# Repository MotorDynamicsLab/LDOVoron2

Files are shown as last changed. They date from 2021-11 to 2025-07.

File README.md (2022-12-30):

# LDO Voron 2 Kit
This repository contains supplementary information/configuration/3d models for the LDO Voron 2 Kit.

We would thank the Voron Design team for all of their hard work and contributions to the 3D printing community.

This repo contains both original and derivative works from the Voron project, 
which is licensed GPLv3. This repo therefore is also licensed under the terms 
of the GNU Public License, verison 3.

GPLv3 License Attributions:

https://github.com/VoronDesign/Voron-Trident
https://github.com/VoronDesign/Voron-2
https://github.com/VoronDesign/Voron-Stealthburner

For more information and support:

https://vorondesign.com

https://discord.gg/voron

https://docs.ldomotors.com

https://www.ldomotion.com

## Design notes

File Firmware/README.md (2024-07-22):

# LDO Voron 2 Configs

## octopus-printer-rev-a.cfg

This contains mainboard configs for LDO V2.4 kits Rev.A & Rev.B

## octopus-printer-rev-c.cfg

This contains mainboard configs for LDO V2.4 kits Rev.C. Changes include:

- Disable mini12864 display, kit now uses a 4.3inch touch panel
- Change chamber thermistor type to ATC Semitec 104NT, kit now uses externally mounted thermistor
- Change extruder gear ratio to 50:10, kit now ships with clockwork 2 by default
- Add configs for Stealthburner neopixels

## leviathan-printer-rev-d.cfg

This contains mainboard configs for LDO V2.4 kits Rev.D

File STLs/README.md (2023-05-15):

# STLs for LDO Kit
This directory contains STL files specific to the LDO kit.

## Plug Panel 1.2mm (Deprecated as of V2.4R2)
This part replaces the `plug_panel` part from the official [Voron repo](https://github.com/VoronDesign/Voron-2/tree/Voron2.4/STLs/VORON2.4/Electronics_Compartment/Plug_Panel). This part adapts specifically to 1.2mm AC inlets for a better fit.

## Nozzle Probe LDO
This part replaces the `nozzle_probe` part from the official [Voron repo](https://github.com/VoronDesign/Voron-2/tree/Voron2.4/STLs/VORON2.4/Z_Endstop). This part allows for an LDO Z Endstop PCB to be used.

## Handlebar Spacer
This optional part offsets the top panel thickness and helps mount the included aluminium handle bar.

## Z Rail stop
An optional part that stops the linear rail carts from falling off the Z rails.

## Exhaust Cover
If you decide to build the Nevermore internal circulation filter, print this exhaust cover to seal the back panel.

## LED PCB Spacer
This part helps mount the LED splitter PCB to the 2020 extrusion.

## Toolhead Breakout PCB Bracket
This part helps mount the toolhead breakout PCB. Print an additional DIN rail clip to attach to this part.

## LDO Bestagon Insert
An (optional) LDO Logo that inserts into the hexagonal holes of the skirts.

## Beefy Raspberry Pi Mount
This mount uses two DIN clips for a more secure grip on DIN rails. 

## Z Belt Cover A LED
This is a remix of the original Z Belt Cover but leaves a small opening for the LED cable to pass through.

## CW2 Offset Chain Anchor
This is the same part as the official chain anchor with an additional M3 insert hole that offsets the end of the X cable chain slightly. Moving the left two holes may result in better clearance when using the cable chain provided in the LDO V2 or Trident kits.

## CW2 PCB Cover for Captive Screw
This part is a slight modification of hartk's [Clockwork 2 PCB cover with thermistor](https://github.com/VoronDesign/Voron-Hardware/blob/master/Stealthburner_Toolhead_PCB/STLs/cable_cover_pcb_with_thermistor.stl). It is designed to be used in conjunction with a captive M3x8 screw, so that the screw does not fall out when the PCB cover is opened.

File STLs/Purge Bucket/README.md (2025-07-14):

# Nozzle scrubber
Our kits provide a brass brush which you can use to convert to a nozzle scrubber using this [mod](https://github.com/VoronDesign/VoronUsers/tree/main/orphaned_mods/edwardyeeks/Decontaminator_Purge_Bucket_%26_Nozzle_Scrubber).
Since our build plate sits higher than typical voron beds, you should use modified files here.

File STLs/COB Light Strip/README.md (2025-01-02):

# COB Light Strip Mount
This is an easy and fast to print mount for COB (chip on the board) LED strips, which are included in LDO Voron kits starting from Rev.D. These LED strips have built-in light diffusion which produces a softer lighting effect for your printer. 
- The STLs come in three sizes (50/100/150mm) that allow you to combine into different lengths to match your LED strip. 
- The provided Fusion 360 source file is parametric to allow for any arbitrary length for the mount. 

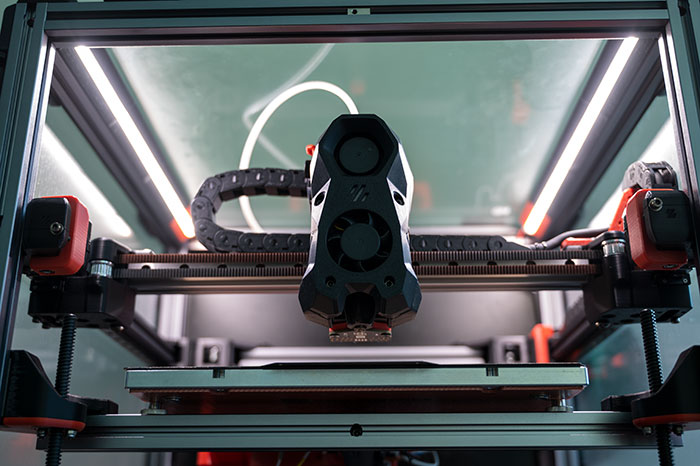
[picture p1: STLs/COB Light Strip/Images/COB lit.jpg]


## Printing for LDO kits
The following are recommend print counts for different LDO Voron kits. Note that you can always substitude 50mm variant and 100mm variant with a single 150mm variant.

### Voron 2.4-300 Kit
Print 6x cob_light_strip_mount_100mm 

### Voron 2.4-350 Kit
Print 6x cob_light_strip_mount_100mm + 2x cob_light_strip_mount_50mm

### Voron Trident-250 Kit
Print 6x cob_light_strip_mount_100mm + 2x cob_light_strip_mount_50mm

### Voron Trident-300 Kit
Print 8x cob_light_strip_mount_100mm

## Assembly
Each mount is a two piece assembly (for easy printing). Use 2x M3 Heatsets and 2x M3x6 FHCS screws two assemble the two pieces together. Use 2x M3x8 SHCS to install the part to the side of a 2020 extrusion.

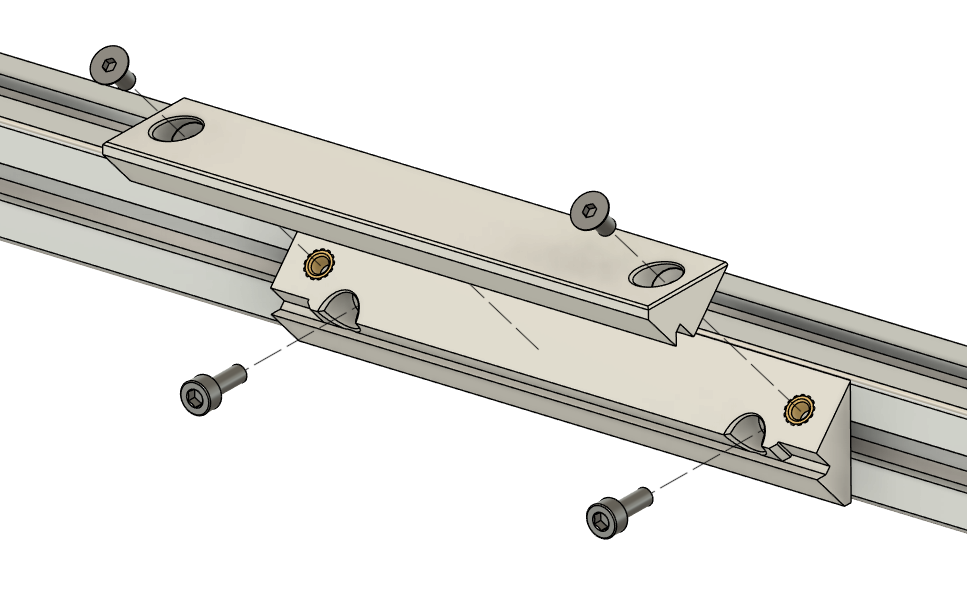
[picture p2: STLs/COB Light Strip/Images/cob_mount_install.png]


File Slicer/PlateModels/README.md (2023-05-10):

# Slicer Plate Models & Textures
This folder contains models and textures that can be used in SuperSlicer or PrusaSlicer. Open Printer Settings->General->Bed Shape. 
- Under Texture, select the svg file appropriate to your build plate size ("300_ldo_texture.svg" for a 300mm plate)
- Under Model, select the stl file appropriate to your build plate size ("Voron_300_Build_Plate.stl" for a 300mm plate)

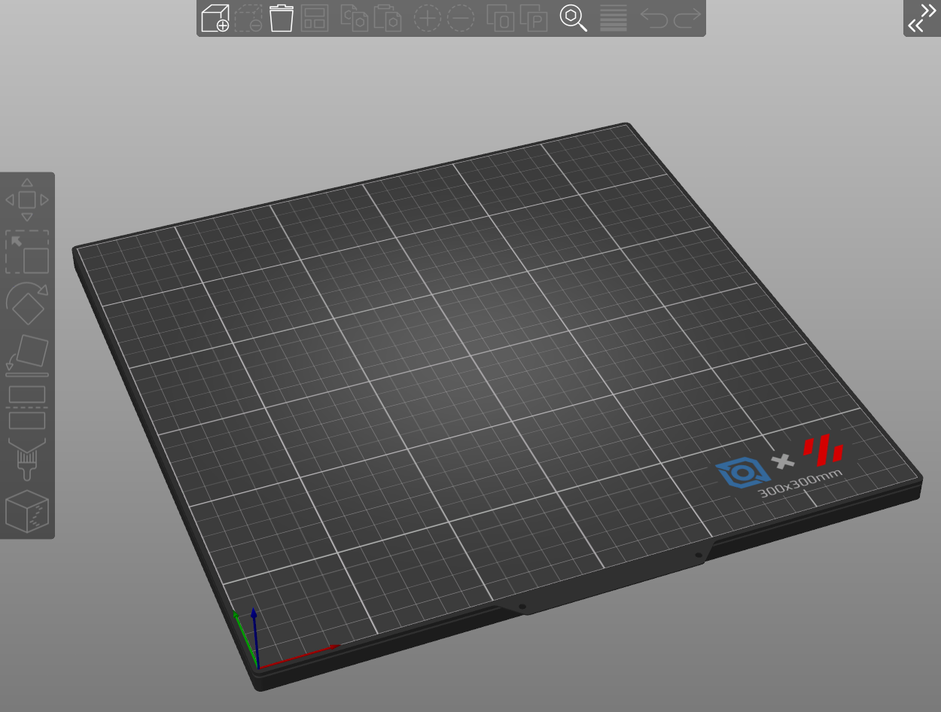
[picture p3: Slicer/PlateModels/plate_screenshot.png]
Screenshot of the LDO custom slicer plate


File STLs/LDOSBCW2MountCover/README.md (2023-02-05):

# LDO Steathburner + Clockwork 2 + LDO Toolhead PCB

## THIS MOD NO LONGER REQUIRED for LDO V2.4 Rev. C - the kit includes the Stealthburner PCBs and works with the stock parts.

For assembly directions please follow our guide [LDO Motion](https://www.ldomotion.com/p/guide/18295873486194241).

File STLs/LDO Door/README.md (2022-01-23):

# LDO Door
This directory contains STL files for an alternative door mounting design.

## Screw Hinge
The screw hinge uses M3 screws instead of a print in place hinge design. We recommend using three hinges per door. M3x40 SHCS screws are recommended, however M3x30 or Mx35 screws also work. 

## Handles
These handles are of the same design as the original voron door handles but longer. handle_a and handle_b are simply mirrors of each other. handle_b_nameplate contains a recess to embed an LDO kit number nameplate (use superglue to attach the nameplate).

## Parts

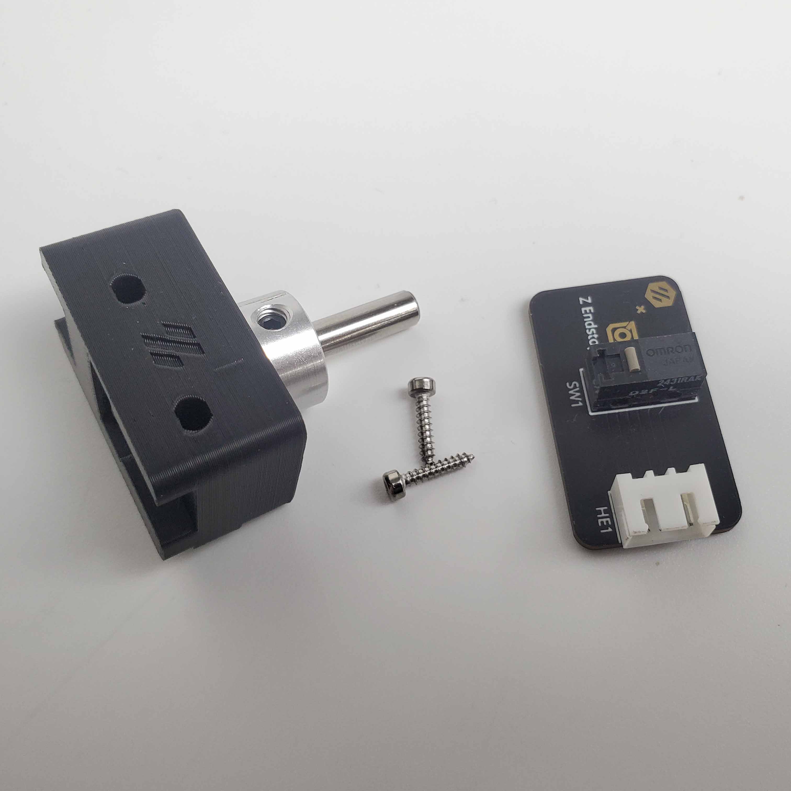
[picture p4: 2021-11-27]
Images/WiringGuide/z_stop_parts.jpg

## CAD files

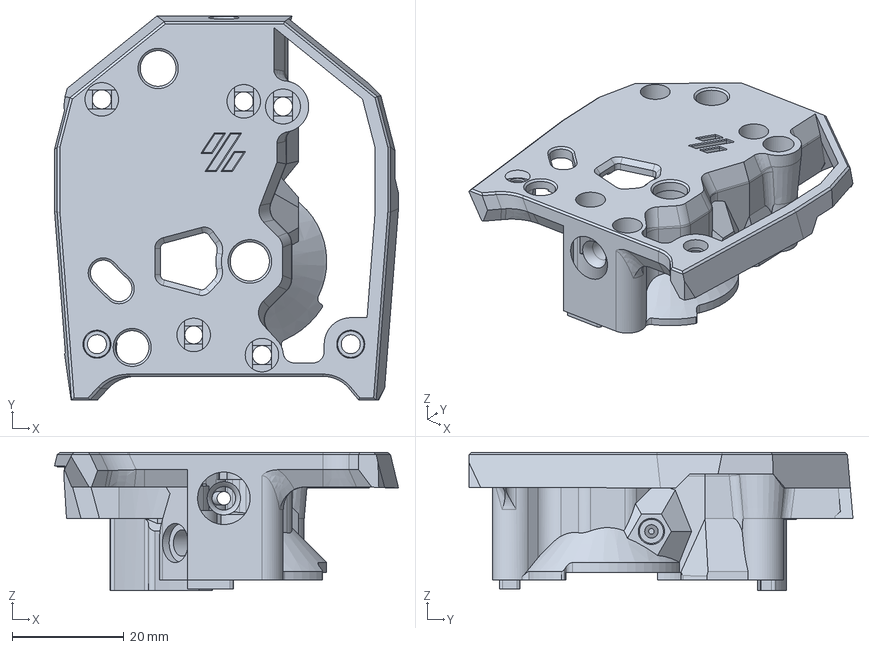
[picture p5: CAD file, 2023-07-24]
STLs/LDOSBCW2MountCover/main_body.step
61.5 x 68.7 x 24.7 mm
LDO AB PCB Assembly

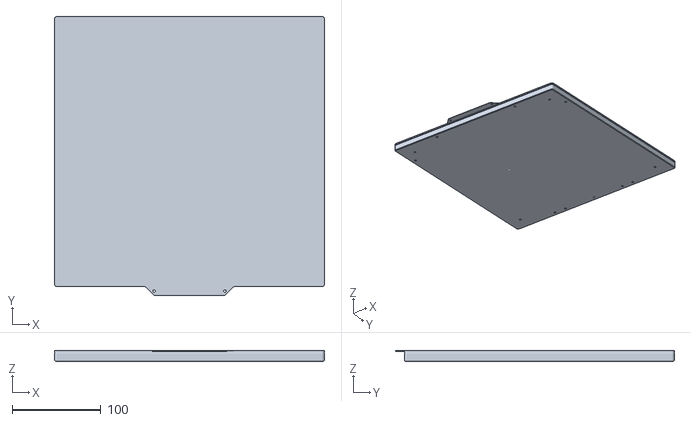
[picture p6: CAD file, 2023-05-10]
Slicer/PlateModels/Voron_300_Build_Plate.stl
305.0 x 315.0 x 11.9

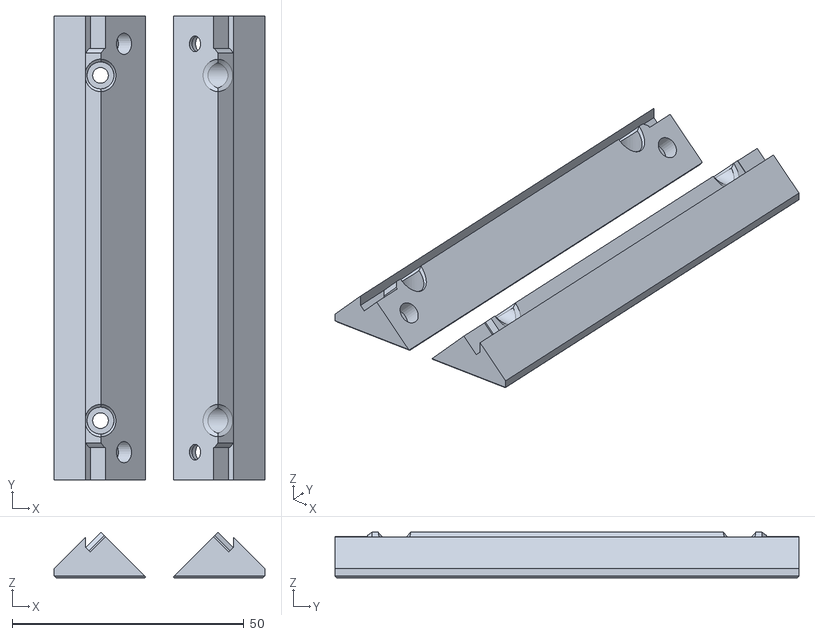
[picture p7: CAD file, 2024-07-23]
STLs/COB Light Strip/cob_light_strip_mount_100mm.stl
45.4 x 100.0 x 9.87

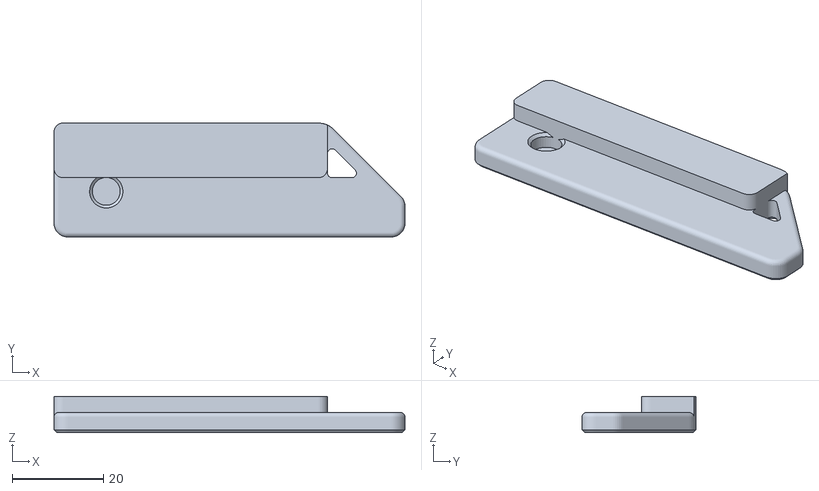
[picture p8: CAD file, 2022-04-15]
STLs/LDO Door/handle_b_nameplate.stl
77.0 x 25.0 x 7.90

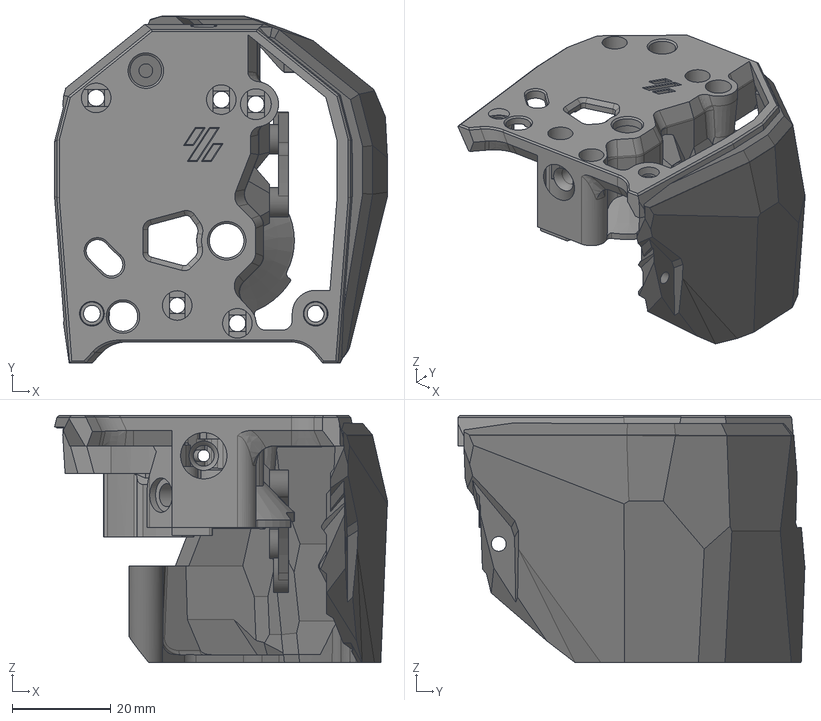
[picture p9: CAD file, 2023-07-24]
STLs/LDOSBCW2MountCover/Stealthburner_CW2_LDOPCB.step
67.6 x 70.4 x 50.2 mm
pcb_spacer v2 v9
cable_cover_for_pcb v9
main_body

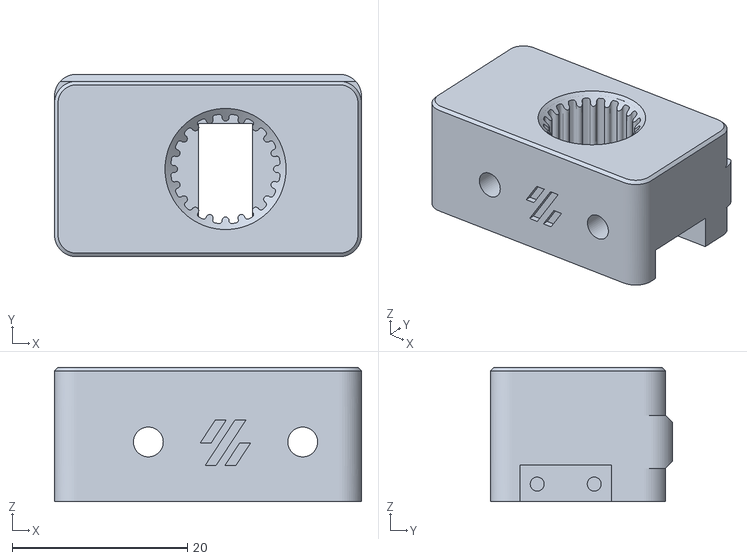
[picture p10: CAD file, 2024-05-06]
STLs/nozzle_probe_ldo.stl
35.0 x 20.8 x 15.3

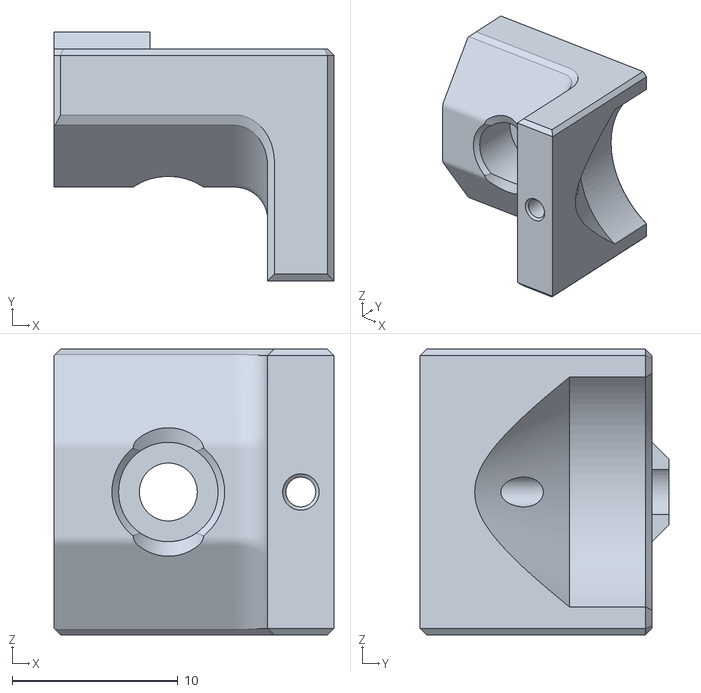
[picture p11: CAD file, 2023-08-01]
STLs/Purge Bucket/individual_sheet_stop.stl
16.9 x 15.0 x 17.3

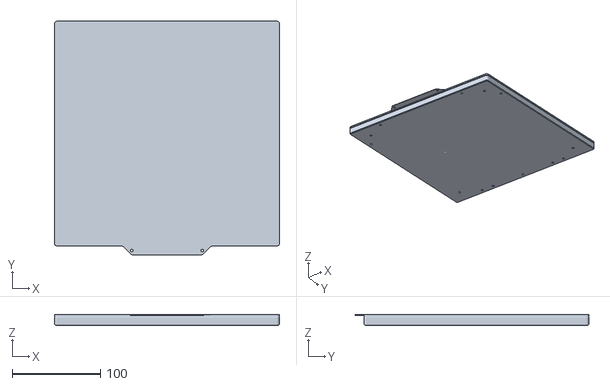
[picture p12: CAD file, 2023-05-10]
Slicer/PlateModels/Voron_250_Build_Plate.stl
255.0 x 265.0 x 11.9

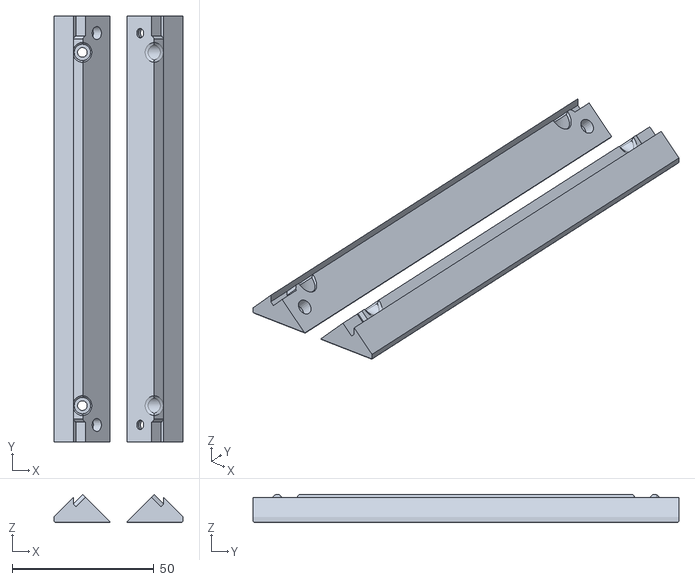
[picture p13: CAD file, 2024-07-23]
STLs/COB Light Strip/cob_light_strip_mount_150mm.stl
45.4 x 150.0 x 9.87

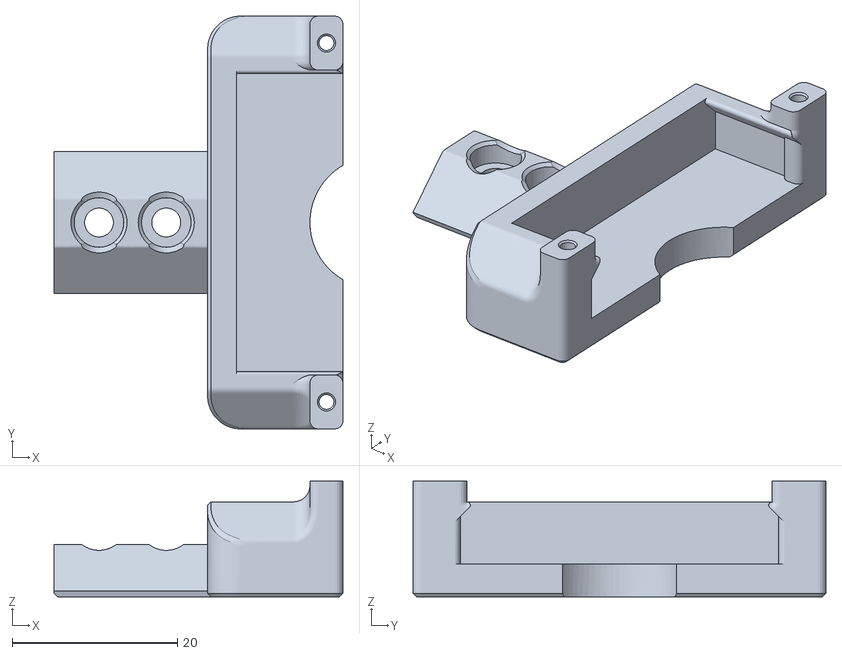
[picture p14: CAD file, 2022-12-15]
STLs/Purge Bucket/brush_holder_sheet_stop.stl
35.0 x 50.0 x 14.0

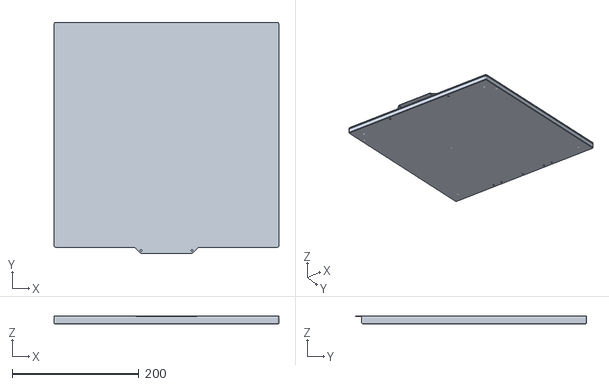
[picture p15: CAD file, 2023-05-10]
Slicer/PlateModels/Voron_350_Build_Plate.stl
355.0 x 365.0 x 11.9

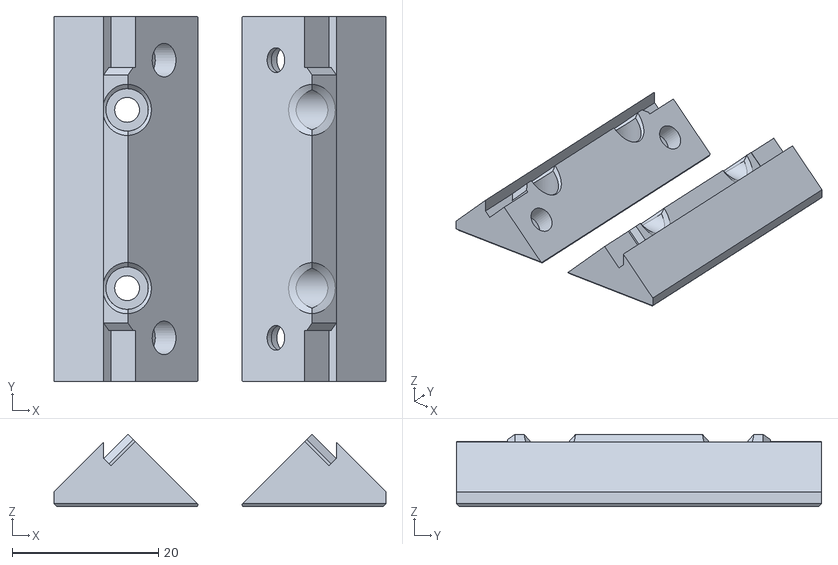
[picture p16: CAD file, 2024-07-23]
STLs/COB Light Strip/cob_light_strip_mount_50mm.stl
45.4 x 50.0 x 9.87

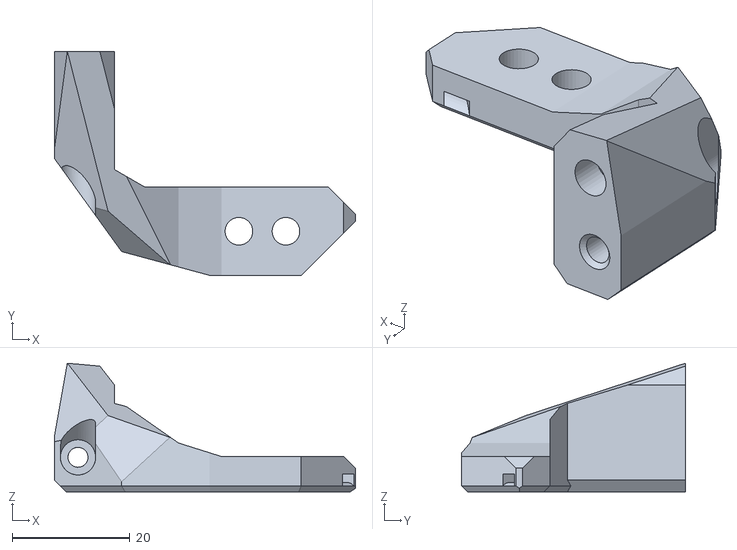
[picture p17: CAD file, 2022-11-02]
STLs/cw2_offset_chain_anchor.stl
51.2 x 38.0 x 21.9

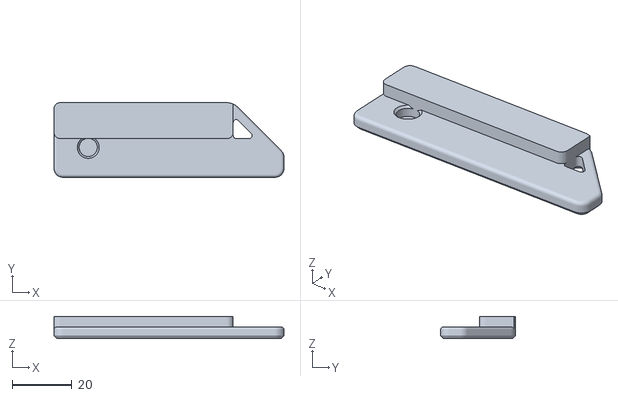
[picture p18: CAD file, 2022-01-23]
STLs/LDO Door/handle_b.stl
77.0 x 25.0 x 7.50

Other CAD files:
STLs/LDOSBCW2MountCover/pcb_spacer.step
STLs/LDO Door/handle_a_x2.stl
STLs/LDOSBCW2MountCover/cable_cover_for_pcb.step
STLs/z_belt_cover_a_led.stl
STLs/Beefy Raspberry Bracket.f3d
STLs/COB Light Strip/COB Light Strip Mount.f3d
STLs/CW2 Offset Chain Anchor.f3d
STLs/CW2 PCB Cover for Captive Screw.f3d
STLs/Exhaust Cover.f3d
STLs/Handlebar Spacer.f3d
STLs/LDO Bestagon Insert.f3d
STLs/LDO Door/Handle Nameplate.f3d
STLs/LDO Door/Handle.f3d
STLs/LDO Door/Screw Hinge.f3d
STLs/LDO Door/screw_hinge_x3.stl
STLs/LDOSBCW2MountCover/LDOSBCW2Cover.step
STLs/LDOSBCW2MountCover/LDOSBCW2Cover.stl
STLs/LDOSBCW2MountCover/LDOSBCW2Mount.step
STLs/LDOSBCW2MountCover/LDOSBCW2Mount.stl
STLs/LDOSBCW2MountCover/LDOSBCW2MountCover.3mf
STLs/LDOSBCW2MountCover/Stealthburner_CW2_LDOPCB.3mf
STLs/LDOSBCW2MountCover/cable_cover_for_pcb.stl
STLs/LDOSBCW2MountCover/deprecated/LDOSBCW2Cover.step
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

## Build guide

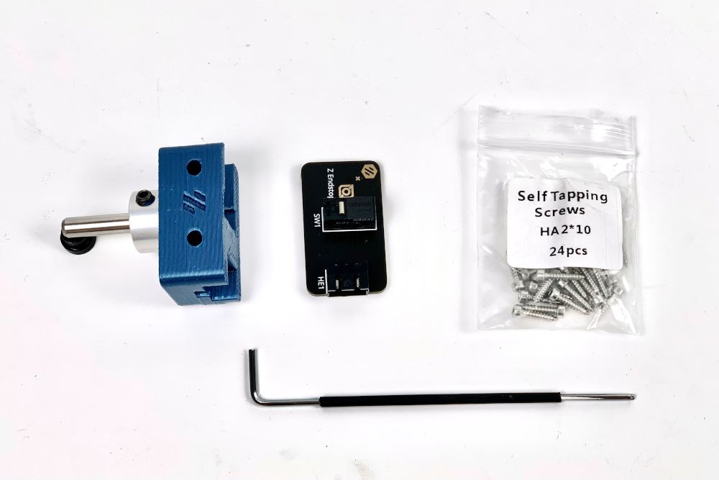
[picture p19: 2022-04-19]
Images/WiringGuide/z_stop_install_1.jpg

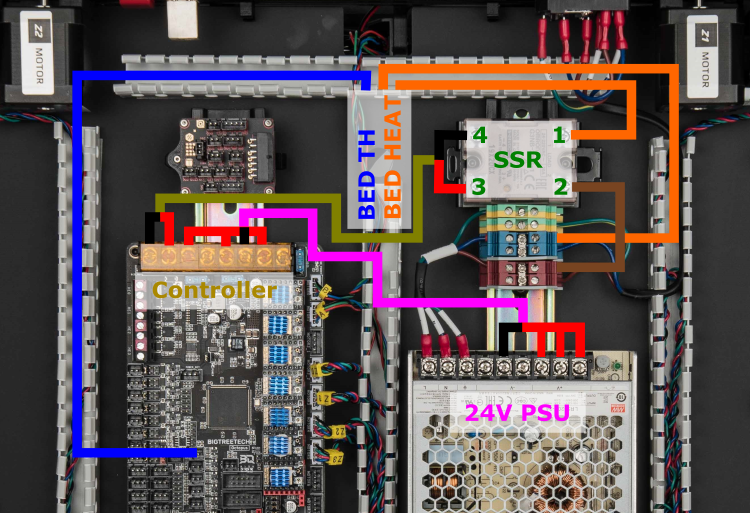
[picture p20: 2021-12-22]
Images/WiringGuide/s08_mapping.png

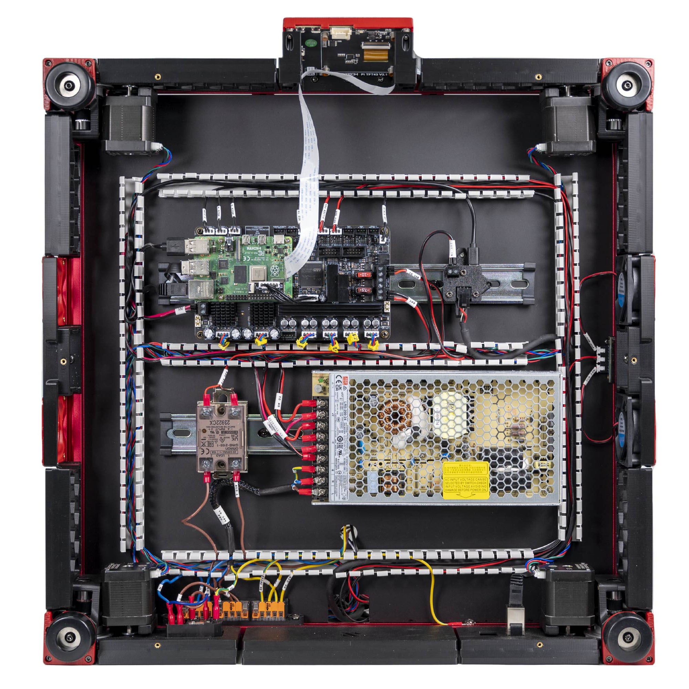
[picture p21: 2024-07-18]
Images/WiringGuide/RevD/VS8_Misc.jpg

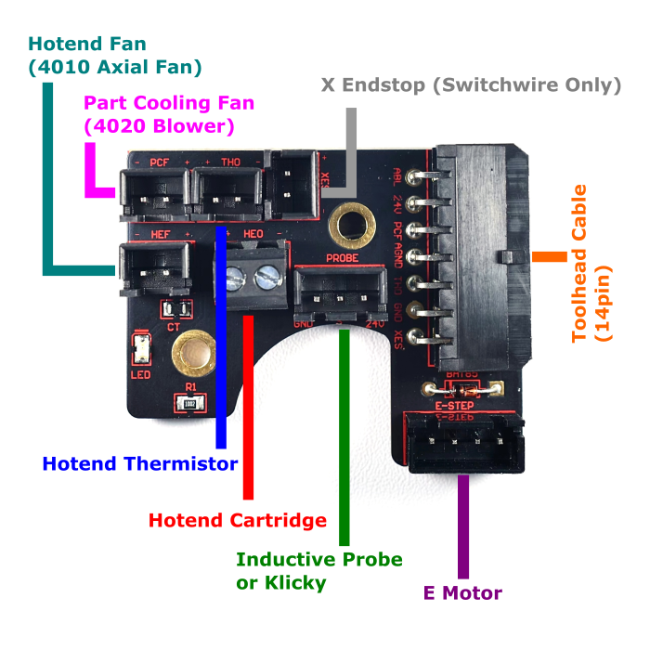
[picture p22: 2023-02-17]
Images/WiringGuide/ab_pcb_mapping.png

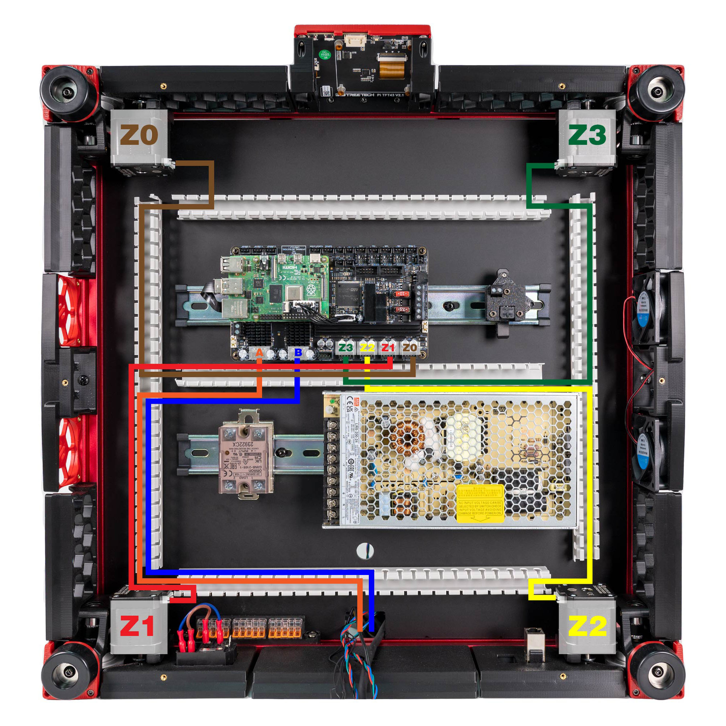
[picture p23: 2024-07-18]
Images/WiringGuide/RevD/S1_mapping.jpg

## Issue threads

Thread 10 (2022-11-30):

Info about mounting the toolhead PCB for SBCW2 missing from Voron 2.4 Build Notes

Carl-Wilhelm, 2022-11-30:
There should be a note that links to the [LDO Toolhead Wiring Kit](https://docs.ldomotors.com/en/voron/toolhead_harness) from the [Build Notes/FAQ](https://docs.ldomotors.com/en/voron/voron2/build-faq) section. I spent a LOT of time trying to figure out how to use the Toolhead PCB that came with the LDO kit before i stumbled upon that link.

camerony, 2022-12-24:
Thank for the feedback.  I've added a link.

Closed 2022-12-24.

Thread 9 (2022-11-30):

Issue with bolt clearence LDOSBCW2Cover.step

Carl-Wilhelm, 2022-11-30:
The button head bolts hits the "chamfer" on the side of the hole. The clearance on the official Voron parts is about 0,3-0,5mm larger.
Se attached picture.
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

Also the hole is oval in the CAD file and should be corrected.

See differences in CAD files:
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

camerony, 2022-12-24:
Thanks for the feedback.  I'll look into this.

camerony, 2023-03-08:
This now deprecated.

Closed 2023-03-08.

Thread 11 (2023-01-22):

Misaligned slot in in LDO SB2 CW2 PCB spacer

jagerman, 2023-01-22:
I printed the CW2 PCB spacer, but the slot to accommodate the soldered pins doesn't line up with the pins on the PCB that came with my LDO Trident kit.  I had to modify it to move to slow towards the flat-head screw hole to make it work.  (Photo incoming).

jagerman, 2023-01-22:
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

I had to modify the part to move to slot towards the side with the nut to make it work.

camerony, 2023-03-08:
fixed

Closed 2023-03-08.

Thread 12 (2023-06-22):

Purge bucket files don't include mounting bracket

maxim-kukushkin, 2023-06-22:
The assembly instructions indicate that it's possible to build a purge bucket with a brush holder using the materials provided in the kit. There're also custom files under STLs/PurgeBucket to accommodate the taller heatbed.

However, it doesn't include anything for mounting the purge bucket. The original [extension bracket](https://github.com/VoronDesign/VoronUsers/blob/master/orphaned_mods/printer_mods/edwardyeeks/Decontaminator_Purge_Bucket_%26_Nozzle_Scrubber/STLs/extension_bracket_v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) doesn't seem to be applicable to the provided architecture of Voron Trident (the photos there show a completely different gantry).

It also doesn't seems possible to find a bracket in any other available sources.

So photos or alternative STLs would be very much appreciated

cr0Kz, 2023-09-17:
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

I ended up using this version instead [Trident mount for Decontaminator Purge Bucket & Nozzle Scrubber](https://www.printables.com/model/174526-trident-mount-for-decontaminator-purge-bucket-nozz).

I am trying to tweak the macro now. I will reply to this issue once I figure it out.

torndar, 2024-03-09:
About to try to print and install this. Did you get things figured out?

It looks like I should print these 3 for the LDO Voron Trident kit
- https://www.printables.com/model/174526-trident-mount-for-decontaminator-purge-bucket-nozz
- https://github.com/MotorDynamicsLab/LDOVoron2/blob/main/STLs/Purge%20Bucket/brush_holder_sheet_stop.stl
- https://github.com/VoronDesign/VoronUsers/blob/master/orphaned_mods/printer_mods/edwardyeeks/Decontaminator_Purge_Bucket_%26_Nozzle_Scrubber/STLs/purge_bucket_250mm_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 (maybe the 300mm version of this one?)

torndar, 2024-03-13:
For the record the 3 models I linked above worked. However, the bucket was rather loose, even after putting magnets in it, so I added foam to the inner edges to pad between the bracket arm and the bucket. That seems to be working pretty well.

Closed 2024-08-06.

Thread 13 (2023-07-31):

individual sheetstop requires supports

Pyromuffin, 2023-07-31:
that's a pretty gnarly overhang. Is this intended to be printed with supports?

cneshi, 2023-08-01:
Thanks for the heads up, seems like the orientation of the stl file was wrong. I have since fixed it.

Closed 2023-08-01.

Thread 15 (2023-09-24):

Errors in config template

wineds, 2023-09-24:
Please consider editing your octopus-printer-rev-c.cfg template as follows :

1.  Line 306, Inductive probe pin needs a pullup (^) or will frequently result in retries and probe tolerance errors.  This was VERY difficult to diagnose.
2.  Direction of extruder motor was wrong with my kit.  I had to reverse it in your config (!).

Closed 2024-08-06.

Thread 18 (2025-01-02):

Cob Strip Light Mount: No assembly instructions

rrittenhouse, 2025-01-02:
Regarding this: https://github.com/MotorDynamicsLab/LDOVoron2/blob/main/STLs/COB%20Light%20Strip/README.md

Would it be possible to get a quick photo posted to the documentation about HOW these fit together and attach to the frame?

Thank you!

camerony, 2025-01-02:
Done, this has been updated

Closed 2025-01-02.

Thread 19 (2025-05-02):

Duplicate quad_gantry_level speed settings in leviathan-printer-rev-d.cfg

morlan, 2025-05-02:
I just noticed that there are two different speed settings under the quad_gantry_level section. Which one was intended by LDO, 100 mm/s or 200 mm/s?

camerony, 2025-07-14:
Fixed, it should be 100.

Closed 2025-07-14.

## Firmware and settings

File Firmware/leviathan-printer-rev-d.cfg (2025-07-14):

# This file contains common pin mappings for the LDO Voron 2.4 Rev. D kit
# See docs/Config_Reference.md for a description of parameters.

## Voron Design VORON 2.4 250/300/350mm Leviathan V1.1 + Nitehawk-SB config

## *** THINGS TO CHANGE/CHECK: ***
## MCU paths                            [mcu] section
## Thermistor types                     [extruder] and [heater_bed] sections - See https://www.klipper3d.org/Config_Reference.html#common-thermistors for common thermistor types
## Z Endstop Switch location            [safe_z_home] section
## Homing end position                  [gcode_macro G32] section
## Z Endstop Switch  offset for Z0      [stepper_z] section
## Probe points                         [quad_gantry_level] section
## Min & Max gantry corner postions     [quad_gantry_level] section
## PID tune                             [extruder] and [heater_bed] sections
## Probe pin                            [probe] section
## Fine tune E steps                    [extruder] section

[mcu]
##  Obtain definition by "ls -l /dev/serial/by-id/" then unplug to verify
##--------------------------------------------------------------------
serial: /dev/serial/by-id/{REPLACE WITH YOUR SERIAL}
restart_method: command
##--------------------------------------------------------------------

[mcu nhk]
##  Obtain definition by "ls -l /dev/serial/by-id/" then unplug to verify
##--------------------------------------------------------------------
serial: /dev/serial/by-id/{REPLACE WITH YOUR SERIAL}
restart_method: command
##--------------------------------------------------------------------

[printer]
kinematics: corexy
max_velocity: 300  
max_accel: 10000
max_z_velocity: 15          #Max 15 for 12V TMC Drivers, can increase for 24V
max_z_accel: 350
square_corner_velocity: 5.0

#####################################################################
#   X/Y Stepper Settings
#####################################################################

##  B Stepper - Left
##  Connected to HV STEPPER 0
##  Endstop connected to X-ENDSTOP
[stepper_x]
step_pin: PB10
dir_pin: !PB11
enable_pin: !PG0
rotation_distance: 40
microsteps: 32
full_steps_per_rotation:400  #set to 200 for 1.8 degree stepper
endstop_pin: PC1
position_min: 0
##--------------------------------------------------------------------

##  Uncomment below for 250mm build
#position_endstop: 250
#position_max: 250

##  Uncomment for 300mm build
#position_endstop: 300
#position_max: 300

##  Uncomment for 350mm build
#position_endstop: 350
#position_max: 350

##--------------------------------------------------------------------
homing_speed: 25   #Max 100
homing_retract_dist: 5
homing_positive_dir: true

##  Make sure to update below for your relevant driver (2209 or 5160)
[tmc5160 stepper_x]
cs_pin: PE15
spi_bus: spi4
#diag0_pin: ^!PG1
interpolate: false
run_current: 0.8
sense_resistor: 0.075
stealthchop_threshold: 0

##  A Stepper - Right
##  Connected to HV STEPPER 1
##  Endstop connected to Y-ENDSTOP
[stepper_y]
step_pin: PF15
dir_pin: !PF14
enable_pin: !PE9
rotation_distance: 40
microsteps: 32
full_steps_per_rotation:400  #set to 200 for 1.8 degree stepper
endstop_pin: PC2
position_min: 0
##--------------------------------------------------------------------

##  Uncomment for 250mm build
#position_endstop: 250
#position_max: 250

##  Uncomment for 300mm build
#position_endstop: 300
#position_max: 300

##  Uncomment for 350mm build
#position_endstop: 350
#position_max: 350

##--------------------------------------------------------------------
homing_speed: 25  #Max 100
homing_retract_dist: 5
homing_positive_dir: true

##  Make sure to update below for your relevant driver (2209 or 5160)
[tmc5160 stepper_y]
cs_pin: PE11
spi_bus: spi4
#diag0_pin: ^!PE10
interpolate: false
run_current: 0.8
sense_resistor: 0.075
stealthchop_threshold: 0
 
#####################################################################
#   Z Stepper Settings
#####################################################################

## Z0 Stepper - Front Left
##  Connected to STEPPER 0
##  Endstop connected to Z-ENDSTOP
[stepper_z]
step_pin: PD4
dir_pin: !PD3
enable_pin: !PD7
rotation_distance: 40
gear_ratio: 80:16  
microsteps: 32
endstop_pin: PC3
##  Z-position of nozzle (in mm) to z-endstop trigger point relative to print surface (Z0)
##  (+) value = endstop above Z0, (-) value = endstop below
##  Increasing position_endstop brings nozzle closer to the bed
##  After you run Z_ENDSTOP_CALIBRATE, position_endstop will be stored at the very end of your config
position_endstop: -0.5
##--------------------------------------------------------------------

##  Uncomment below for 250mm build
#position_max: 230

##  Uncomment below for 300mm build
#position_max: 280

##  Uncomment below for 350mm build
#position_max: 330

##--------------------------------------------------------------------
position_min: -5
homing_speed: 8
second_homing_speed: 3
homing_retract_dist: 3

##  Make sure to update below for your relevant driver (2209 or 5160)
[tmc2209 stepper_z]
uart_pin: PD5
#diag_pin: ^!PD6
interpolate: false
run_current: 0.8
sense_resistor: 0.110
stealthchop_threshold: 0

##  Z1 Stepper - Rear Left
##  Connected to STEPPER 1
[stepper_z1]
step_pin: PC12
dir_pin: PC11
enable_pin: !PD2
rotation_distance: 40
gear_ratio: 80:16 
microsteps: 32

##  Make sure to update below for your relevant driver (2209 or 5160)
[tmc2209 stepper_z1]
uart_pin: PD0
#diag_pin: ^!PD1
interpolate: false
run_current: 0.8
sense_resistor: 0.110
stealthchop_threshold: 0

##  Z2 Stepper - Rear Right
##  Connected to STEPPER 2
[stepper_z2]
step_pin: PC9
dir_pin: !PC8
enable_pin: !PC10
rotation_distance: 40
gear_ratio: 80:16 
microsteps: 32

##  Make sure to update below for your relevant driver (2209 or 5160)
[tmc2209 stepper_z2]
uart_pin: PA8
#diag_pin: ^!PA15
interpolate: false
run_current: 0.8
sense_resistor: 0.110
stealthchop_threshold: 0

##  Z3 Stepper - Front Right
##  Connected to STEPPER 3
[stepper_z3]
step_pin: PG7
dir_pin: PG6
enable_pin: !PC7
rotation_distance: 40
gear_ratio: 80:16 
microsteps: 32

##  Make sure to update below for your relevant driver (2209 or 5160)
[tmc2209 stepper_z3]
uart_pin: PG8
#diag_pin: ^!PC6
interpolate: false
run_current: 0.8
sense_resistor: 0.110
stealthchop_threshold: 0

#####################################################################
#   Extruder
#####################################################################

##  Connected to STEPPER 0
##  Heater - HEATER
##  Thermistor - TH0
[extruder]
step_pin: nhk:gpio23
dir_pin: nhk:gpio24
enable_pin: !nhk:gpio25
##  Update value below when you perform extruder calibration
##  If you ask for 100mm of filament, but in reality it is 98mm:
##  rotation_distance = <previous_rotation_distance> * <actual_extrude_distance> / 100
##  22.6789511 is a good starting point
rotation_distance: 22.6789511   #Bondtech 5mm Drive Gears
##  Update Gear Ratio depending on your Extruder Type
##  Use 50:10 for Stealthburner/Clockwork 2
##  Use 50:17 for Afterburner/Clockwork (BMG Gear Ratio)
##  Use 80:20 for M4, M3.1
gear_ratio: 50:10               #BMG Gear Ratio
microsteps: 32
full_steps_per_rotation: 200    #200 for 1.8 degree, 400 for 0.9 degree
nozzle_diameter: 0.400
filament_diameter: 1.75
heater_pin: nhk:gpio9
## Check what thermistor type you have. See https://www.klipper3d.org/Config_Reference.html#common-thermistors for common thermistor types.
## Use "Generic 3950" for NTC 100k 3950 thermistors
sensor_type: ATC Semitec 104NT-4-R025H42G
sensor_pin: nhk:gpio29
pullup_resistor: 2200
min_temp: 10
max_temp: 270
max_power: 1.0
min_extrude_temp: 170
control = pid
pid_kp = 26.213
pid_ki = 1.304
pid_kd = 131.721
##  Try to keep pressure_advance below 1.0
#pressure_advance: 0.05
##  Default is 0.040, leave stock
#pressure_advance_smooth_time: 0.040

##  E0 on MOTOR6
##  Connected to STEPPER 4
[tmc2209 extruder]
uart_pin: nhk:gpio0
tx_pin: nhk:gpio1
interpolate: false
run_current: 0.5
sense_resistor: 0.100
stealthchop_threshold: 0


#####################################################################
#   Bed Heater
#####################################################################

[heater_bed]
##  SSR Pin - HEATBED
##  Thermistor - TH1
heater_pin: PG11
sensor_type: ATC Semitec 104NT-4-R025H42G
sensor_pin: PA2
pullup_resistor: 2200
##  Adjust Max Power so your heater doesn't warp your bed. Rule of thumb is 0.4 watts / cm^2 .
max_power: 0.6
min_temp: 0
max_temp: 120
control: pid
pid_kp: 58.437
pid_ki: 2.347
pid_kd: 363.769

#####################################################################
#   Probe
#####################################################################

[probe]
##  Inductive Probe
##  Connected to Z-PROBE
##  This probe is not used for Z height, only Quad Gantry Leveling
pin: nhk:gpio10
x_offset: 0
y_offset: 25.0
z_offset: 0
speed: 10.0
samples: 3
samples_result: median
sample_retract_dist: 3.0
samples_tolerance: 0.006
samples_tolerance_retries: 3
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

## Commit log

2021-09-02 add plug_panel_1.2mm and nozzle_probe_ldo
    [nozzle_probe_ldo.f3d, nozzle_probe_ldo.stl, plug_panel_1.2mm.f3d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]
2021-11-01 update nozzle probe
    [nozzle_probe_ldo.f3d, nozzle_probe_ldo.stl]
2021-11-01 add z rail stop
    [Z Rail Stop.f3d, z_rail_stop_x4.stl]
2021-11-01 add handlebar spacer
    [Handlebar Spacer.f3d, handlebar_spacer_x4.stl]
2021-11-01 add exhaust cover
    [Exhaust Cover.f3d, exhaust_cover.stl]
2021-11-01 add LED PCB spacer
    [LED PCB Spacer.f3d, led_pcb_spacer.stl]
2021-11-01 fix wording: 2020 rail -> 2020 extrusion
2021-11-04 reorient stl files
    [exhaust_cover.stl, nozzle_probe_ldo.stl]
2021-11-09 slightly increase height of nozzle probe
    [nozzle_probe_ldo.f3d, nozzle_probe_ldo.stl]
2021-11-18 add Toolhead Breakout PCB Bracket
    [Toolhead Breakout PCB Bracket.f3d, toolhead_breakout_pcb_bracket.stl]
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2021-11-26 update handlebar_spacer to accept roll-in nuts
    [Handlebar Spacer.f3d, handlebar_spacer_x4.stl]
2021-11-26 add octopus-printer.cfg
    [octopus-printer.cfg]
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2021-11-27 lower the top surface of the nozzle probe block by 1.5mm
    [nozzle_probe_ldo.f3d, nozzle_probe_ldo.stl]
2021-12-17 add cross pattern to counterbore feature in exhaust_cover to aid with printing
    [Exhaust Cover.f3d, exhaust_cover.stl]
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2021-12-27 add missing nozzle probe route to s14_mapping
2021-12-30 add LDO hexagon insert for side skirts
    [LDO Bestagon Insert.f3d, ldo_bestagon_insert.stl]
2021-12-30 update STL/README.md with parts that were missing descriptions
2021-12-31 flip default orientation of nozzle_probe_ldo.stl
    [nozzle_probe_ldo.stl]
2022-01-10 update Handlebar Spacer to accommodate extra foam.
    [Handlebar Spacer.f3d, handlebar_spacer_x4.stl]
2022-01-11 update Handlebar Spacer with better styling
    [Handlebar Spacer.f3d, handlebar_spacer_x4.stl]
2022-01-23 add alternative LDO door mounting solution
    [Handle Nameplate.f3d, Handle.f3d, Screw Hinge.f3d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]
2022-01-26 fix orientation of screw_hinge_x3.stl
    [screw_hinge_x3.stl]
2022-02-01 Turn off interpolation and increase microstep values of steppers in config. convert all tabs to spaces
    [octopus-printer.cfg]
2022-02-09 enlarge outline of exhaust_cover to allow use of foam tape for sealing
    [Exhaust Cover.f3d, exhaust_cover.stl]
2022-02-19 upload V2.4R2 inlet temporarily
    [power_inlet_IECGS_1.2mm.stl]
2022-02-24 remove power_inlet_IECGS_1.2mm.stl upon official release of V24R2
    [power_inlet_IECGS_1.2mm.stl]
2022-02-24 add Beefy Raspberry Bracket
    [Beefy Raspberry Bracket.f3d, beefy_raspberry_bracket.stl]
2022-02-24 fix incorrect orientation of beefy_raspberry_bracket.stl
    [beefy_raspberry_bracket.stl]
2022-02-25 update octopus-printer.cfg to match the latest settings in the voron repo
    [octopus-printer.cfg]
2022-02-25 make minor description changes to header block in octopus-printer.cfg
    [octopus-printer.cfg]
2022-04-15 limit default fan speed of controller fan to reduce jet engine noise
    [octopus-printer.cfg]
2022-04-15 add support to Handle Nameplate for flatter overhang
    [Handle Nameplate.f3d, handle_b_nameplate.stl]
2022-04-17 Z Belt Cover LED Pass-Thru
    [Z Belt Cover A LED.f3d, z_belt_cover_a_led.stl]
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2022-05-16 enable stealthchop on Z motors to reduce noise
    [octopus-printer.cfg]
2022-05-17 reduce z max position to match the official voron repo. change z_hop_speed to 10 in attempt to reduce motor noise
    [octopus-printer.cfg]
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2022-08-08 Update thermistor types for extruder and bed heater
    [octopus-printer.cfg]
2022-10-10 Added Gear Ratio for CW2
    [octopus-printer.cfg]
2022-11-02 add CW2 Offset Chain Anchor
    [CW2 Offset Chain Anchor.f3d, cw2_offset_chain_anchor.stl]
2022-12-15 add nozzle brush mod
    [Brush Holder Sheet Stop.f3d, Individual Sheet Stop.f3d, brush_holder_sheet_stop.stl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]
2022-12-24 Update octopus-printer.cfg
    Sync with Voron Design V2.4 configuration.
    [octopus-printer.cfg]
2023-01-17 New SBCW2 Version 2
    [Stealthburner_CW2_LDOPCBv2.3mf]
2023-01-20 Update to SB Revised
    [LDOSBCW2Cover.step, LDOSBCW2Cover.stl, LDOSBCW2Mount.step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]
2023-01-30 Enlarge solder point slot
    [Stealthburner_CW2_LDOPCB.3mf, pcb_spacer.stl]
2023-01-30 Update solder point slot
    [Stealthburner_CW2_LDOPCB.step, pcb_spacer.step]
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2023-02-16 add missing e motor label in sb_pcb_mapping
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2023-03-17 rename original octopus-printer.cfg to octopus-printer-rev-a.cfg
    [octopus-printer-rev-a.cfg]
2023-03-17 add rev C klipper config, add README to document changes to rev C
    [octopus-printer-rev-c.cfg]
2023-04-08 upload batch of new photos and diagrams for rev C wiring guide
2023-04-16 add octopus power adapter installation diagram, and images for touch screen FFC install
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2023-05-10 add LDO custom slicer models and textures
    [Voron_250_Build_Plate.stl, Voron_300_Build_Plate.stl, Voron_350_Build_Plate.stl]
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2023-05-15 add CW2 PCB Cover for Captive Screw
    [CW2 PCB Cover for Captive Screw.f3d, cw2_pcb_cover_for_captive_screw.stl]
2023-05-31 Rename led_pcb_spacer
    [led_fan_pcb_spacer_x2.stl]
2023-07-24 Update motor_body to match Voron update
    [Stealthburner_CW2_LDOPCB.3mf, Stealthburner_CW2_LDOPCB.step, main_body.step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]
2023-08-01 fix incorrect orientation of individual_sheet_stop.stl
    [individual_sheet_stop.stl]
2024-05-06 modify nozzle_probe_ldo to make pulley easier for insertion
    [nozzle_probe_ldo.f3d, nozzle_probe_ldo.stl]
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2024-07-22 add cfg file for rev d and update readme
    [leviathan-printer-rev-d.cfg]
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2024-07-23 add COB Light Strip Mount for RevD light strips
    [COB Light Strip Mount.f3d, cob_light_strip_mount_100mm.stl, cob_light_strip_mount_150mm.stl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]
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2024-07-23 fix mistakes in pin assignments and title block in printer-leviathan-rev-d.cfg
    [leviathan-printer-rev-d.cfg]
2024-11-19 fix extruder sense_resistor
    [leviathan-printer-rev-d.cfg]
2024-11-25 fix missing configuration(CMFB103F3950FANT)
    [leviathan-printer-rev-d.cfg]
2025-01-20 leviathan-printer-rev-d.cfg add gcode LOAD_FILAMENT and UNLOAD_FILAMENT
    [leviathan-printer-rev-d.cfg]
2026-07-21 fix(leviathan-rev-d): correct fan tachometer pin comments
    - [fan] tachometer_pin comment changed to nhk:gpio17
    - [heater_fan hotend_fan] tachometer_pin comment changed to nhk:gpio16
2026-07-21 feat(leviathan-rev-d): add Nitehawk-SB toolboard config
    - add leviathan-printer-rev-d-sbv2.cfg for Leviathan V1.1 + Nitehawk-SB setup
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
